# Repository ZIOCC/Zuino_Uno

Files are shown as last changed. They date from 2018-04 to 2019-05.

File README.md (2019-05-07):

# Zuino M Uno Microcontroller

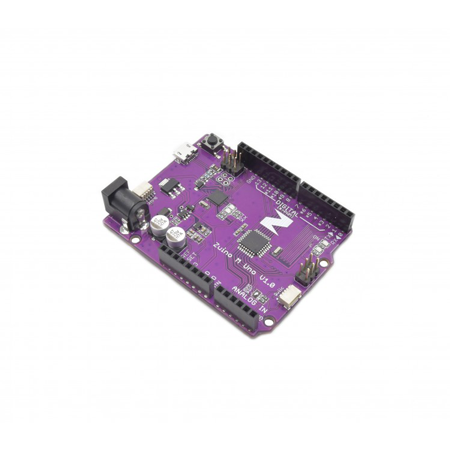
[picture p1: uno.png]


> This product can be available for purchase [here](https://www.smart-prototyping.com/Zuino-M-UNO.html).

#### Description

Based on the ATmega328, this microcontroller is Arduino and Arduino Uno R3-compatible. Our version of this famously popular microcontroller board integrates a Qwiic connector at either end of the PCB, enabling it to be easily connected with other Qwiic-compatible modules.

The Arduino Uno is the board with which many makers get started. It’s comparatively inexpensive, easy to use, and open source. The worldwide collaborative community, coupled with the easy-to-use IDE, are the primary reasons this microcontroller is the nearly ubiquitous introduction to embedded computing for the last decade. 

This board comes with all of the functions and features that you know and love from the Arduino Uno, with the added bonus of on-board Qwiic capability. The familiar header pins will allow you to use it with any Arduino shield or other modules that lack a Qwiic connector.

Note: you cannot power the Zuino M Uno via Qwiic, as it is a 5v device, and does not include a 3.3v-to-5v boost converter.

#### Specification

* Microcontroller: Atmega328P
* Operating Voltage: 5V
* Input Voltage: 7-12V
* Digital I/O Pins: 14 (6 provide PWM output)
* PWM Digital I/O Pins: 6
* Analog Input Pins: 6
* DC Current per I/O Pin: 20 mA
* DC Current for 3.3V Pin and Qwiic: 50 mA
* Flash Memory: 32KB (0.5 KB is used by bootloader)
* SRAM: 2 KB
* EEPROM: 1 KB
* Clock Speed: 16 MHz
* Dimensions:
* Weight: 18.7g (0.66oz)

#### Links

* [PCB Source file](https://github.com/ZIOCC/Zuino_Uno)

> ###### About Zio
> Zio is a new line of open sourced, compact, and grid layout boards, fully integrated for Arduino and Qwiic ecosystem. Designed ideally for wearables, robotics, small-space limitations or other on the go projects. Check out other awesome Zio products [here](https://www.smart-prototyping.com/Zio).

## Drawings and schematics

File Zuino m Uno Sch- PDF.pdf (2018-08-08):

## USB Chip ATMEGA16U2

## DC Power

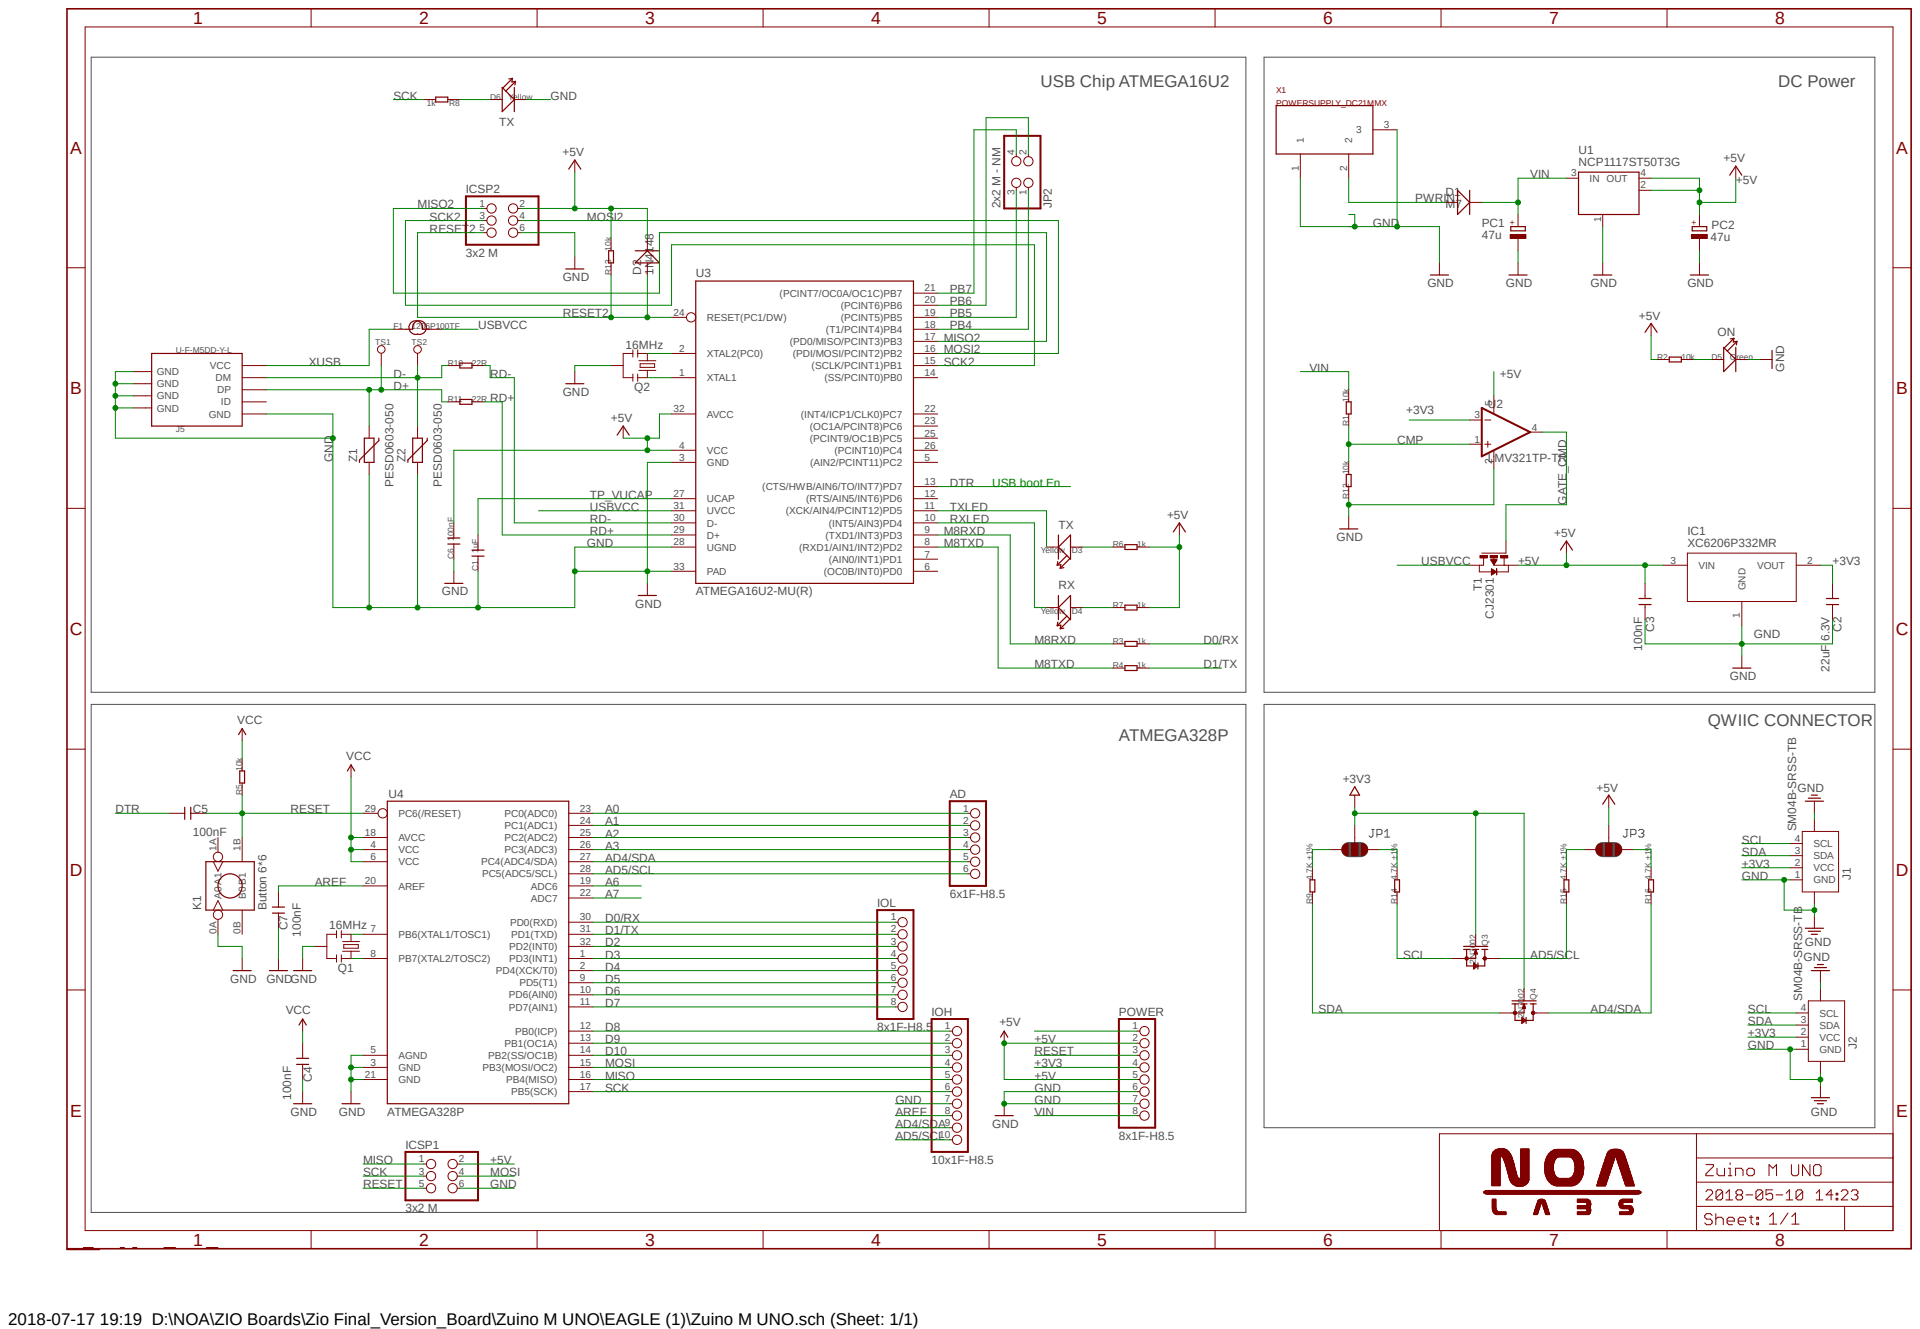
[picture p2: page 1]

VCC GND GND GND GND

2018-07-17 19:19 D:\NOA\ZIO Boards\Zio Final_Version_Board\Zuino M UNO\EAGLE (1)\Zuino M UNO.sch (Sheet: 1/1)

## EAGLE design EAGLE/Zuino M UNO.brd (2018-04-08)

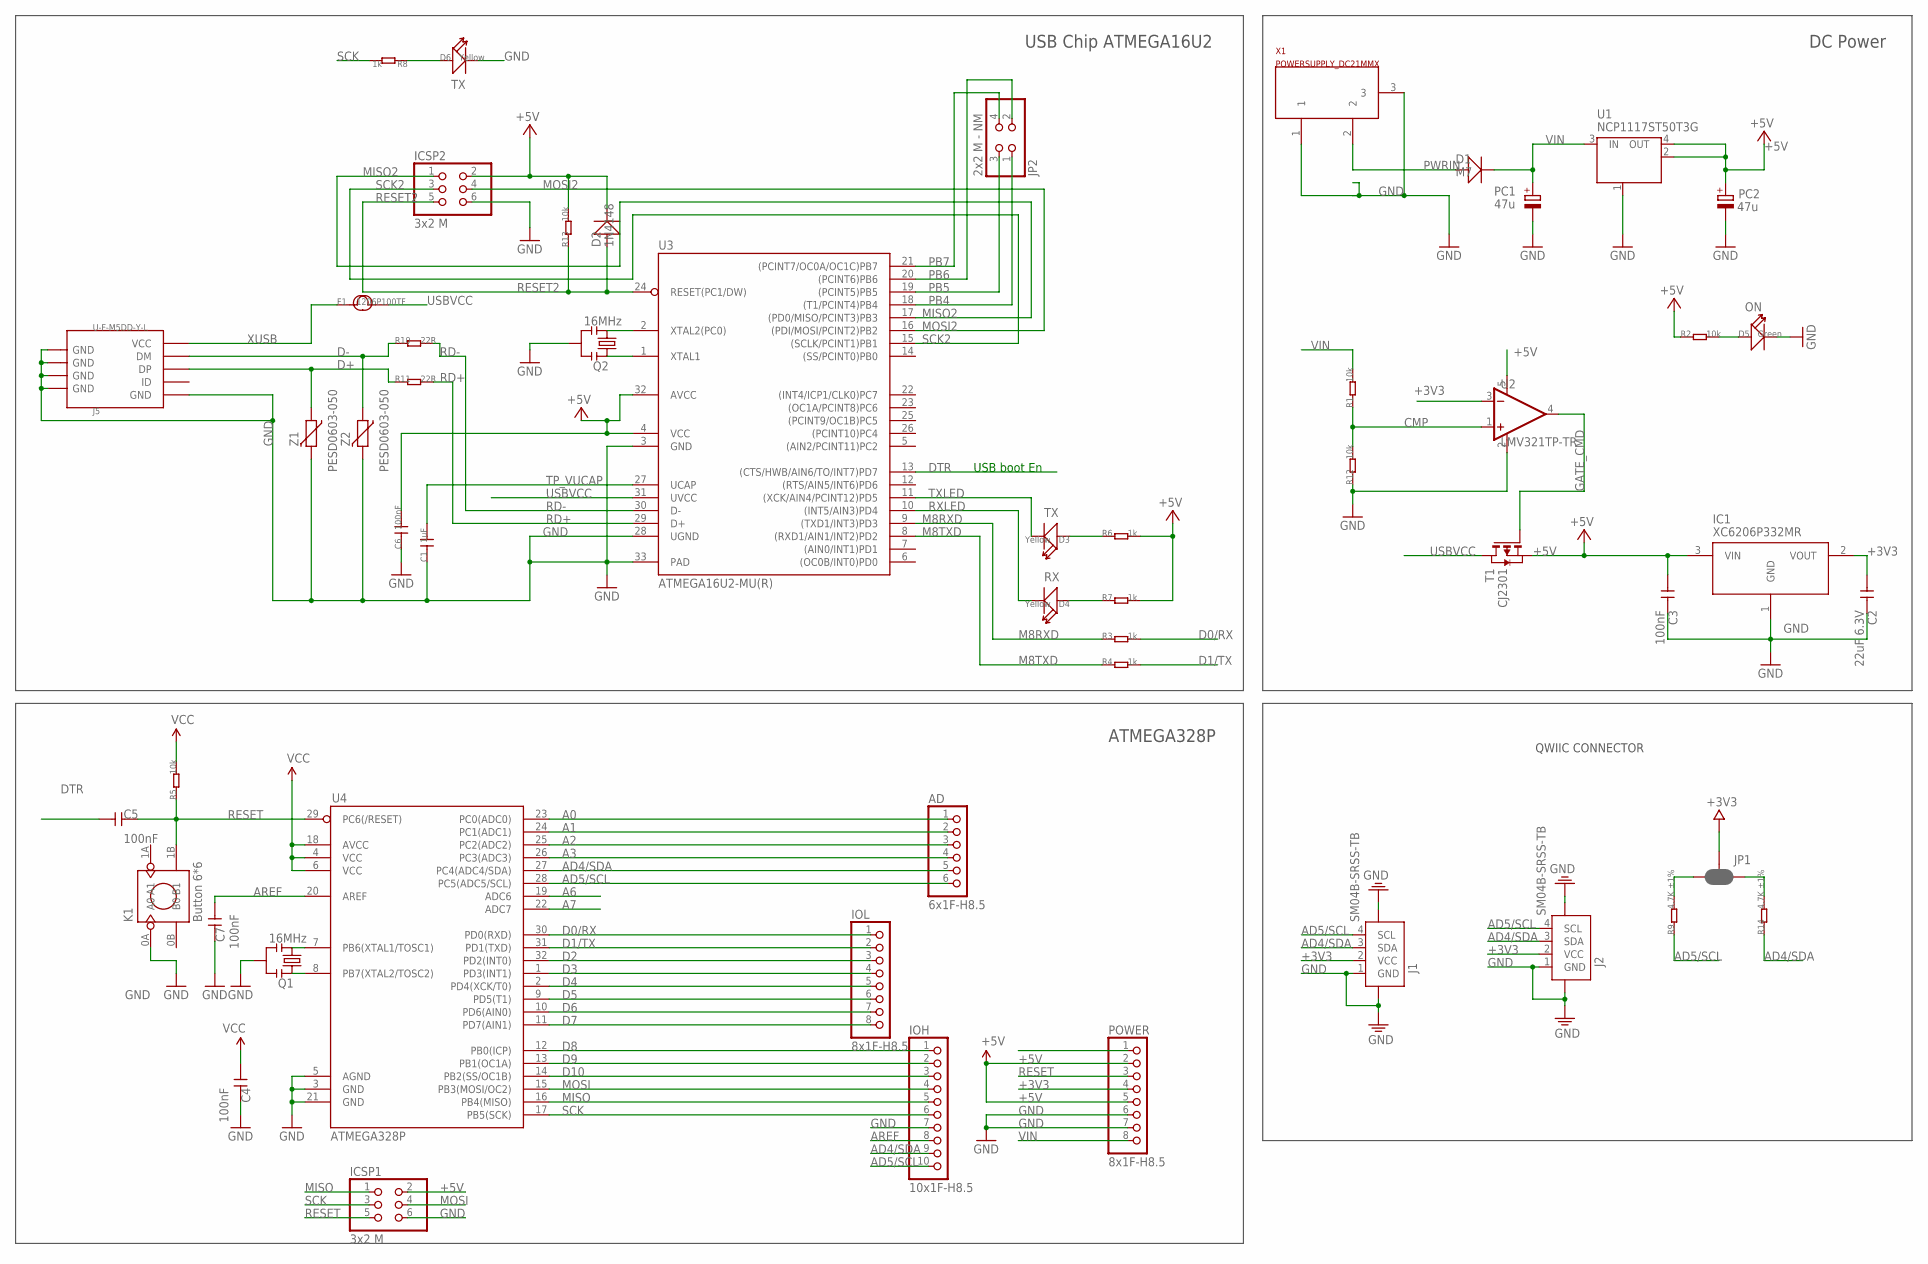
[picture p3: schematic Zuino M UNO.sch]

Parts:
AD: 6x1F-H8.5; 1X06
C1: 1uF; 0603
C2: 22uF 6.3V; 0603
C3, C4, C5, C6, C7: 100nF; 0603
D1: M7; SMA
D2: 1N4148; SOD123
D3, D4, D6: Yellow; LED-0805
D5: Green; LED-0805
F1: 1206P100TF; 1206
IC1: XC6206P332MR; SOT23
ICSP1, ICSP2: 3x2 M; 2X03
IOH: 10x1F-H8.5; 1X10
IOL: 8x1F-H8.5; 1X08
J1, J2: SM04B-SRSS-TB; JST-SH-4P
J5: U-F-M5DD-Y-L; MICRO-SMD
JP1: JUMPER-SMT_3_2-NC_PASTE_SILK; SMT-JUMPER_3_2-NC_PASTE_SILK
JP2: 2x2 M - NM; 2X02
K1: Button 6*6; 4P-SMD-6X6
PC1, PC2: 47u; PANASONIC_D
POWER: 8x1F-H8.5; 1X08
Q1, Q2: 16MHz; RESONATOR-SMD
R1, R2, R5, R12, R13: 10k; 0603
R3, R4, R6, R7, R8: 1k; 0603
R9, R14: 4.7K ±1%; 0603
R10, R11: 22R; 0603
T1: CJ2301; SOT-23
U1: NCP1117ST50T3G; SOT223
U2: LMV321TP-TR; SOT23-5
U3: ATMEGA16U2-MU(R); MLF32
U4: ATMEGA328P; TQFP32-08
X1: POWERSUPPLY_DC21MMX; POWERSUPPLY_DC-21MM
Z1, Z2: PESD0603-050; CT/CN0603

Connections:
+3V3: C2.1, IC1.2 (VOUT), J1.2 (VCC), J2.2 (VCC), JP1.2, POWER.4, U2.3 (IN-)
+5V: C3.1, C4.2, C6.2, D2.-, IC1.3 (VIN), ICSP1.2, ICSP2.2, PC2.+, POWER.2, POWER.5, R2.1, R5.2, R6.2, R7.2, R13.2, T1.2 (S), U1.2 (OUT), U1.4 (OUT), U2.5 (V+), U3.4 (VCC), U3.32 (AVCC), U4.4 (VCC), U4.6 (VCC), U4.18 (AVCC)
A0: AD.1, U4.23 (PC0(ADC0))
A1: AD.2, U4.24 (PC1(ADC1))
A2: AD.3, U4.25 (PC2(ADC2))
A3: AD.4, U4.26 (PC3(ADC3))
A6: U4.19 (ADC6)
A7: U4.22 (ADC7)
AD4/SDA: AD.5, IOH.9, J1.3 (SDA), J2.3 (SDA), R14.1, U4.27 (PC4(ADC4/SDA))
AD5/SCL: AD.6, IOH.10, J1.4 (SCL), J2.4 (SCL), R9.1, U4.28 (PC5(ADC5/SCL))
AREF: C7.2, IOH.8, U4.20 (AREF)
CMP: R1.1, R12.2, U2.1 (IN+)
D0/RX: IOL.1, R3.2, U4.30 (PD0(RXD))
D1/TX: IOL.2, R4.2, U4.31 (PD1(TXD))
D2: IOL.3, U4.32 (PD2(INT0))
D3: IOL.4, U4.1 (PD3(INT1))
D4: IOL.5, U4.2 (PD4(XCK/T0))
D5: IOL.6, U4.9 (PD5(T1))
D6: IOL.7, U4.10 (PD6(AIN0))
D7: IOL.8, U4.11 (PD7(AIN1))
D8: IOH.1, U4.12 (PB0(ICP))
D9: IOH.2, U4.13 (PB1(OC1A))
D10: IOH.3, U4.14 (PB2(SS/OC1B))
D+: J5.D+ (DP), R11.1, Z1.1
D-: J5.D- (DM), R10.1, Z2.1
DTR: C5.2, U3.13 ((CTS/HWB/AIN6/TO/INT7)PD7)
GATE_CMD: T1.3 (G), U2.4 (OUT)
GND: C1.1, C2.2, C3.2, C4.1, C6.1, C7.1, D5.-, D6.-, IC1.1 (GND), ICSP1.6, ICSP2.6, IOH.7, J1.1 (GND), J1.NC1 (5), J1.NC2 (6), J2.1 (GND), J2.NC1 (5), J2.NC2 (6), J5.GND, J5.S1 (GND), J5.S1@1 (GND), J5.S1@2 (GND), J5.S2 (GND), J5.S2@1 (GND), J5.S2@2 (GND), J5.S3 (GND), J5.S3@1 (GND), J5.S3@2 (GND), J5.S4 (GND), J5.S4@1 (GND), J5.S4@2 (GND), K1.0A (A0), PC1.-, PC2.-, POWER.6, POWER.7, Q1.2, Q2.2, R12.1, U1.1 (GND/ADJ), U2.2 (V-), U3.3 (GND), U3.28 (UGND), U3.33 (PAD), U4.3 (GND), U4.5 (AGND), U4.21 (GND), X1.1, X1.3, Z1.2, Z2.2
M8RXD: R3.1, U3.9 ((TXD1/INT3)PD3)
M8TXD: R4.1, U3.8 ((RXD1/AIN1/INT2)PD2)
MISO: ICSP1.1, IOH.5, U4.16 (PB4(MISO))
MISO2: ICSP2.1, U3.17 ((PD0/MISO/PCINT3)PB3)
MOSI: ICSP1.4, IOH.4, U4.15 (PB3(MOSI/OC2))
MOSI2: ICSP2.4, U3.16 ((PDI/MOSI/PCINT2)PB2)
unnamed: D6.+, R8.1
unnamed: D5.+, R2.2
unnamed: Q2.1, U3.1 (XTAL1)
unnamed: JP1.3, R9.2
unnamed: JP1.1, R14.2
unnamed: Q1.1, U4.8 (PB7(XTAL2/TOSC2))
unnamed: Q1.3, U4.7 (PB6(XTAL1/TOSC1))
unnamed: Q2.3, U3.2 (XTAL2(PC0))
unnamed: D4.+, R7.1
unnamed: D3.+, R6.1
PB4: JP2.1, U3.18 ((T1/PCINT4)PB4)
PB5: JP2.3, U3.19 ((PCINT5)PB5)
PB6: JP2.2, U3.20 ((PCINT6)PB6)
PB7: JP2.4, U3.21 ((PCINT7/OC0A/OC1C)PB7)
PWRIN: D1.P$2 (+), X1.2
RD+: R11.2, U3.29 (D+)
RD-: R10.2, U3.30 (D-)
RESET: C5.1, ICSP1.5, K1.1B (B1), POWER.3, R5.1, U4.29 (PC6(/RESET))
RESET2: D2.+, ICSP2.5, R13.1, U3.24 (RESET(PC1/DW))
RXLED: D4.-, U3.10 ((INT5/AIN3)PD4)
SCK: ICSP1.3, IOH.6, R8.2, U4.17 (PB5(SCK))
SCK2: ICSP2.3, U3.15 ((SCLK/PCINT1)PB1)
TP_VUCAP: C1.2, U3.27 (UCAP)
TXLED: D3.-, U3.11 ((XCK/AIN4/PCINT12)PD5)
USBVCC: F1.2, T1.1 (D), U3.31 (UVCC)
VIN: D1.P$1 (-), PC1.+, POWER.8, R1.2, U1.3 (IN)
XUSB: F1.1, J5.VBUS (VCC)

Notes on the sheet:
USB boot En
USB Chip ATMEGA16U2
ATMEGA328P
DC Power
QWIIC CONNECTOR

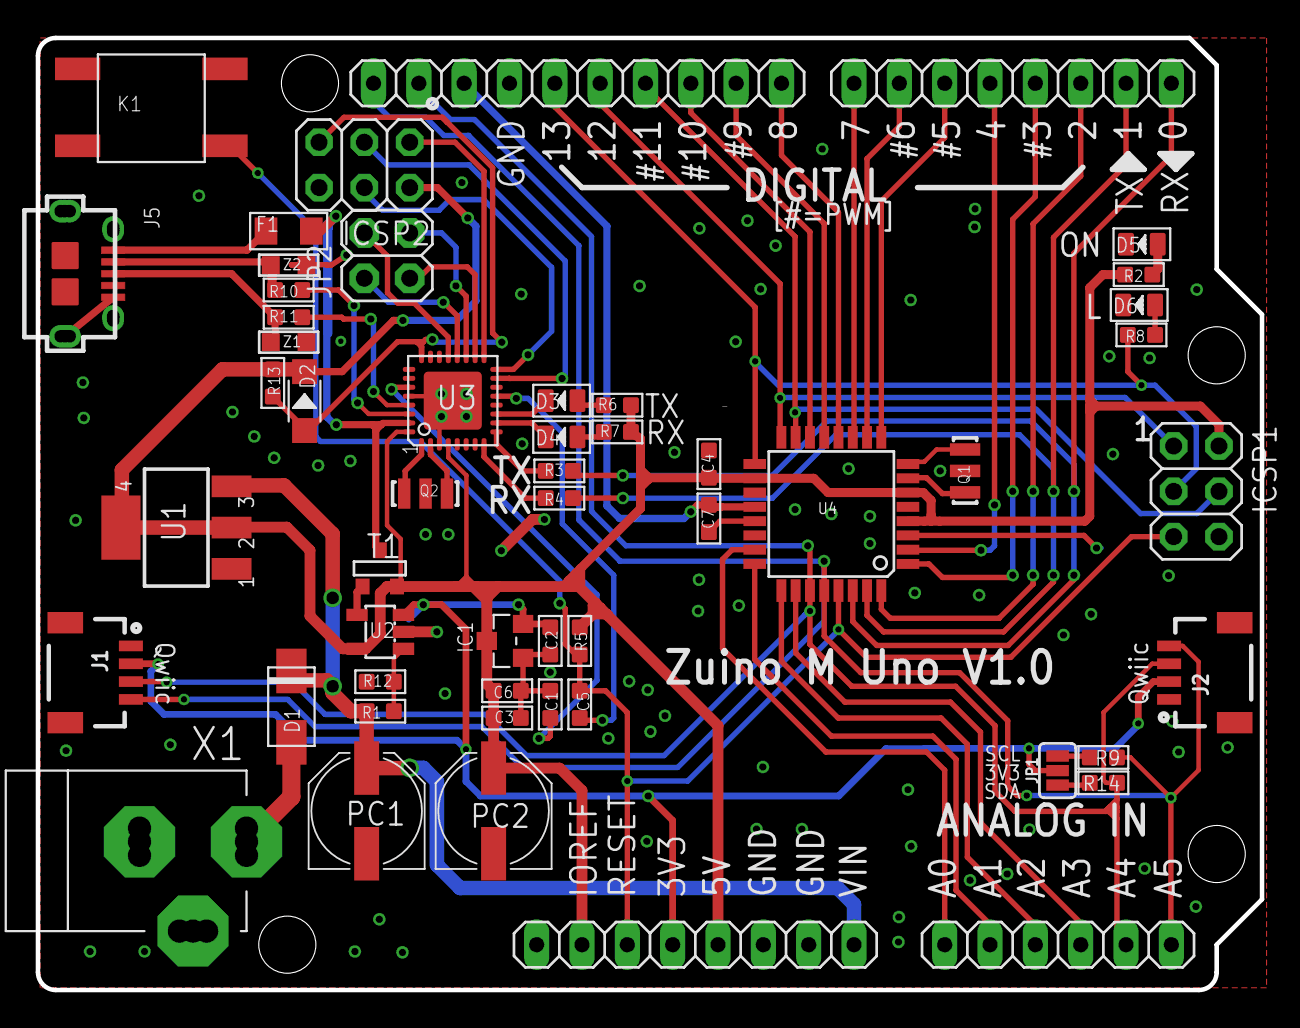
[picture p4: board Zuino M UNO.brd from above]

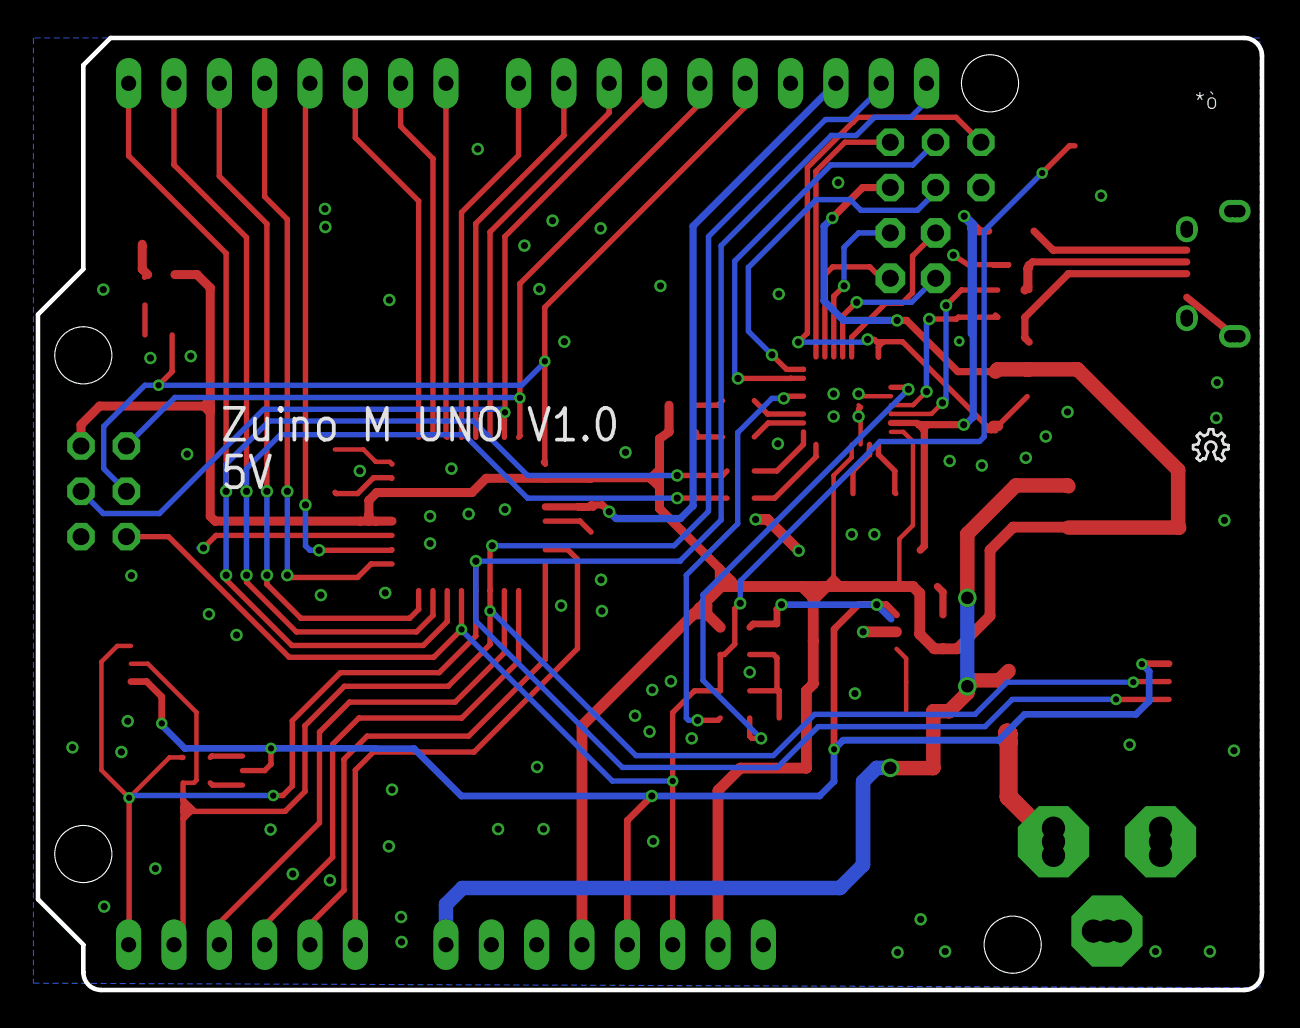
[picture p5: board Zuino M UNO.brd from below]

Board: 2 copper layers, 68.6 x 53.3 mm, 56 parts (2 on the bottom side), 59 nets.

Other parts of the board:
E$13: 12MM
LOGO1: LOGO-OSHW-6MILX0070-NT; OSHW_6X70_NOTEXT
U$1: 10MM

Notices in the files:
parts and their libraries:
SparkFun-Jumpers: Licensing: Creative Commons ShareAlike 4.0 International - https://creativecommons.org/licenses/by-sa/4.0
